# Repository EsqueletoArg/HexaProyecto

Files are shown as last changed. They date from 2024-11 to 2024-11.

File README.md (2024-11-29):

# HexaProyecto

Es  ajedrez de 3x3 casillas, donde se enfrentan 3 peones de ambos bandos para inmovilizar al rival o llegar al otro lado del tablero.

# Software:
* Programado para ser subido en un ESP32, este proyecto cuenta con un algoritmo que actua como el rival de este ajedrez. Este software se encuentra en la carpeta **/Firmware**, en el archivo nombrado "*HexaProyecto.ino*" y fue programado a mano usando Arduino IDE. Si desean construir uno en sus hogares, en las primeras lineas de esta programacion deberían cambiar ciertos valores para que el proyecto pueda conectarse a internet correctamente.

* En cuanto al servidor, se encuentra alojado en la carpeta **/Firmware/Server** en el archivo "*Servidor.js*". Para hacerlo funcionar, necesitamos descargar los programas Node.js y Mosquitto, ambos son descargables de manera gratuita en su respectiva página oficial. 

* Para hacerlo funcionar correctamente, hay que descargar ciertas dependencias en la carpeta donde se encuentre el servidor. Estas dependencias no funcionaran sin Nodejs y/o Mosquitto. Para descargarlas hay que dirigirse al directorio donde se encuentra el archivo "*Servidor.js*" via cmd e introducir los comandos "*npm init -y*" y "*npm install mqtt express body-parser*". Descargar cada dependencia podría tardar un tiempo, pero no de manera significativa.

# Hardware (PCB):
* El hardware de la PCB se encuentra en la carpeta **/Hardware_(PCB)**. Cada archivo dentro de esta carpeta es parte del diseño del PCB, desde el PCB final, hasta el esquema usado como referencia.

* Como el ESP32 está conectado al internet, esto reducía enormemente la cantidad de pines (Entradas y salidas), que podiamos usar. Por eso decidimos hacer una matriz de botones, lo que nos permitio reducir la cantidad de pines usados de 9 a 6.

* Para la placa usamos unos LEDs inteligentes llamados "WS2812", que con cierto nivel de programación son capaces de formar cualquier color. Estos LEDs solo necesitan una fuente de alimentacion de 5V, GND y una entrada de datos. Estos LEDs tambien tienen un cable de salida de datos que nos permitió poner 9 LEDs en serie y, por tanto, usar una sola salida del ESP32.

# Hardware (3D):
* Para el 3D hicimos un marco para encajar la PCB. Si bien puede sonar a que es por motivos de poco esfuerzo, la verdad es otra: Es algo simple, barato y que le permite al PCB relucir todo el esfuerzo que le dedicamos para diseñarlo.

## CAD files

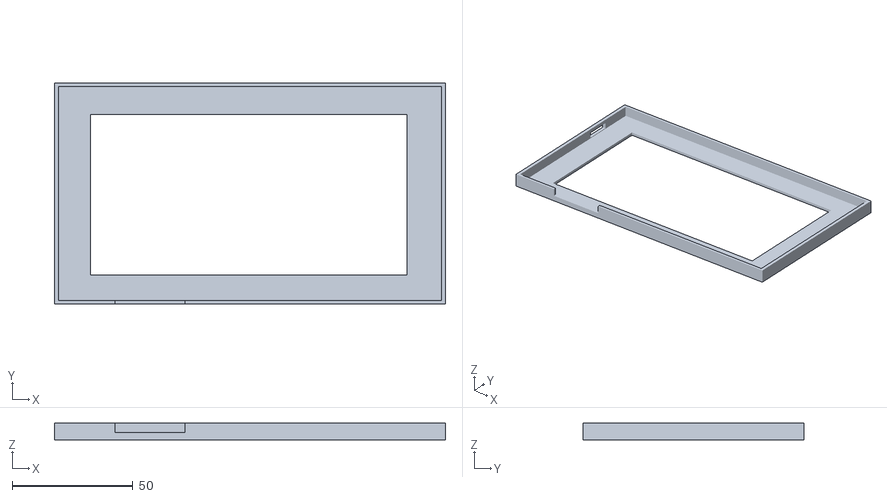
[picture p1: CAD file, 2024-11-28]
Hardware_(3D)/HexaProyecto_3D.stl
162.0 x 91.5 x 7.00

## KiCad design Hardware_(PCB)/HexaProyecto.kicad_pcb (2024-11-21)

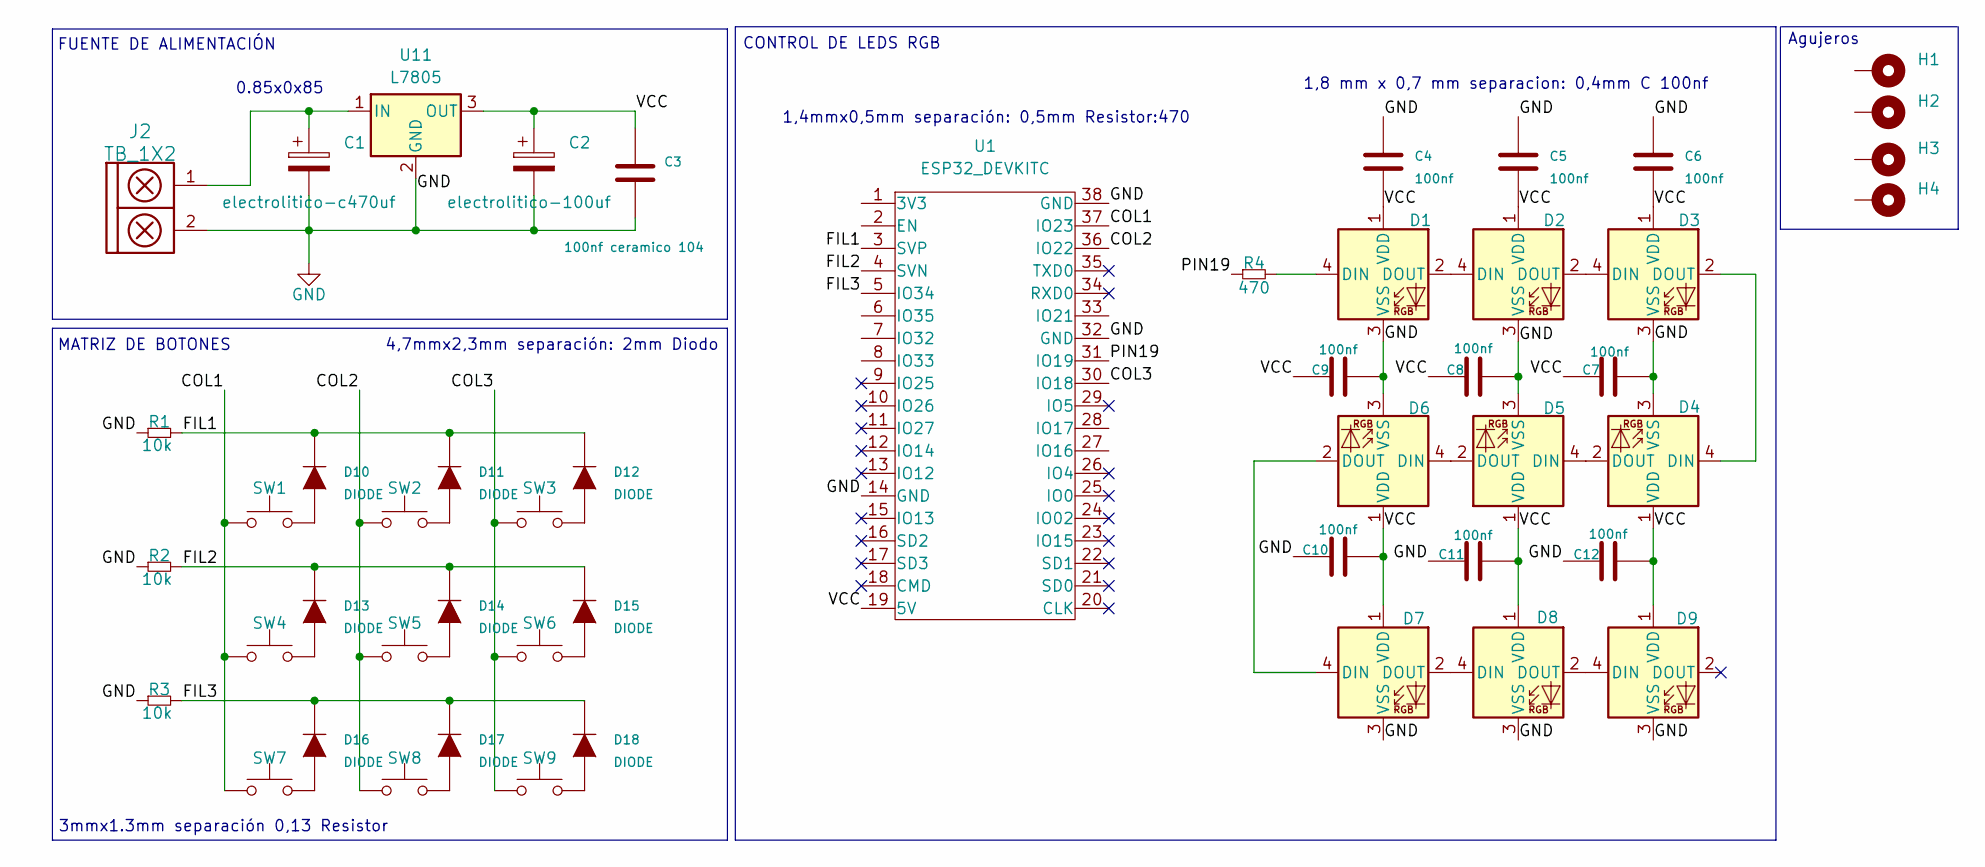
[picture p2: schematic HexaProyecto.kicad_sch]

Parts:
C1: electrolitico-c470uf; CP_Elec_6.3x9.9
C2: electrolitico-100uf; CP_Radial_D8.0mm_P3.50mm
C3: 100nf ceramico 104; CAP_0.1
C4, C5, C6, C7, C8, C9, C10, C11, C12: 100nf; verdadero.capacior.smd.100nf
D1, D2, D3, D4, D5, D6, D7, D8, D9: WS2812B; LED_WS2812B_PLCC4_5.0x5.0mm_P3.2mm
D10, D11, D12, D13, D14, D15, D16, D17, D18: DIODE; Diodo_SMD M7
H1, H2, H3, H4: MountingHole_Pad; Separador_M3_10mm
J2: TB_1X2; TerminalBlock_Altech_AK300-2_P5.00mm
R1, R2, R3: 10k; rrr
R4: 470; R_0603_1608Metric
SW1, SW2, SW3, SW4, SW5, SW6, SW7, SW8, SW9: SW_Push; pushbuttom
U1: ESP32_DEVKITC; ese
U11: L7805; TO-263-2

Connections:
/COL1: SW1.1, SW4.1, SW7.1, U1.37 (IO23)
/COL2: SW2.1, SW5.1, SW8.1, U1.36 (IO22)
/COL3: SW3.1, SW6.1, SW9.1, U1.30 (IO18)
/FIL1: D10.2 (K), D11.2 (K), D12.2 (K), R1.2, U1.3 (SVP)
/FIL2: D13.2 (K), D14.2 (K), D15.2 (K), R2.2, U1.4 (SVN)
/FIL3: D16.2 (K), D17.2 (K), D18.2 (K), R3.2, U1.5 (IO34)
/PIN19: R4.1, U1.31 (IO19)
/VCC: C2.1, C3.2, C4.1, C5.1, C6.1, C7.1, C8.1, C9.1, C10.1, C11.1, C12.1, D1.1 (VDD), D2.1 (VDD), D3.1 (VDD), D4.1 (VDD), D5.1 (VDD), D6.1 (VDD), D7.1 (VDD), D8.1 (VDD), D9.1 (VDD), U1.19 (5V), U11.3 (OUT)
GND: C1.2, C2.2, C3.1, C4.2, C5.2, C6.2, C7.2, C8.2, C9.2, C10.2, C11.2, C12.2, D1.3 (VSS), D2.3 (VSS), D3.3 (VSS), D4.3 (VSS), D5.3 (VSS), D6.3 (VSS), D7.3 (VSS), D8.3 (VSS), D9.3 (VSS), J2.2, R1.1, R2.1, R3.1, U1.14 (GND), U1.32 (GND), U1.38 (GND), U11.2 (GND)
unnamed: D1.4 (DIN), R4.2
unnamed: D1.2 (DOUT), D2.4 (DIN)
unnamed: D2.2 (DOUT), D3.4 (DIN)
unnamed: D3.2 (DOUT), D4.4 (DIN)
unnamed: D4.2 (DOUT), D5.4 (DIN)
unnamed: D5.2 (DOUT), D6.4 (DIN)
unnamed: D6.2 (DOUT), D7.4 (DIN)
unnamed: D7.2 (DOUT), D8.4 (DIN)
unnamed: D8.2 (DOUT), D9.4 (DIN)
unnamed: D10.1 (A), SW1.2
unnamed: D11.1 (A), SW2.2
unnamed: D12.1 (A), SW3.2
unnamed: D13.1 (A), SW4.2
unnamed: D14.1 (A), SW5.2
unnamed: D15.1 (A), SW6.2
unnamed: D16.1 (A), SW7.2
unnamed: D17.1 (A), SW8.2
unnamed: D18.1 (A), SW9.2
unnamed: C1.1, J2.1, U11.1 (IN)

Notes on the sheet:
FUENTE DE ALIMENTACIÓN
0.85x0x85
3mmx1.3mm separación 0,13 Resistor
1,8 mm x 0,7 mm separacion: 0,4mm C 100nf
MATRIZ DE BOTONES
Agujeros
CONTROL DE LEDS RGB
4,7mmx2,3mm separación: 2mm Diodo
1,4mmx0,5mm separación: 0,5mm Resistor:470

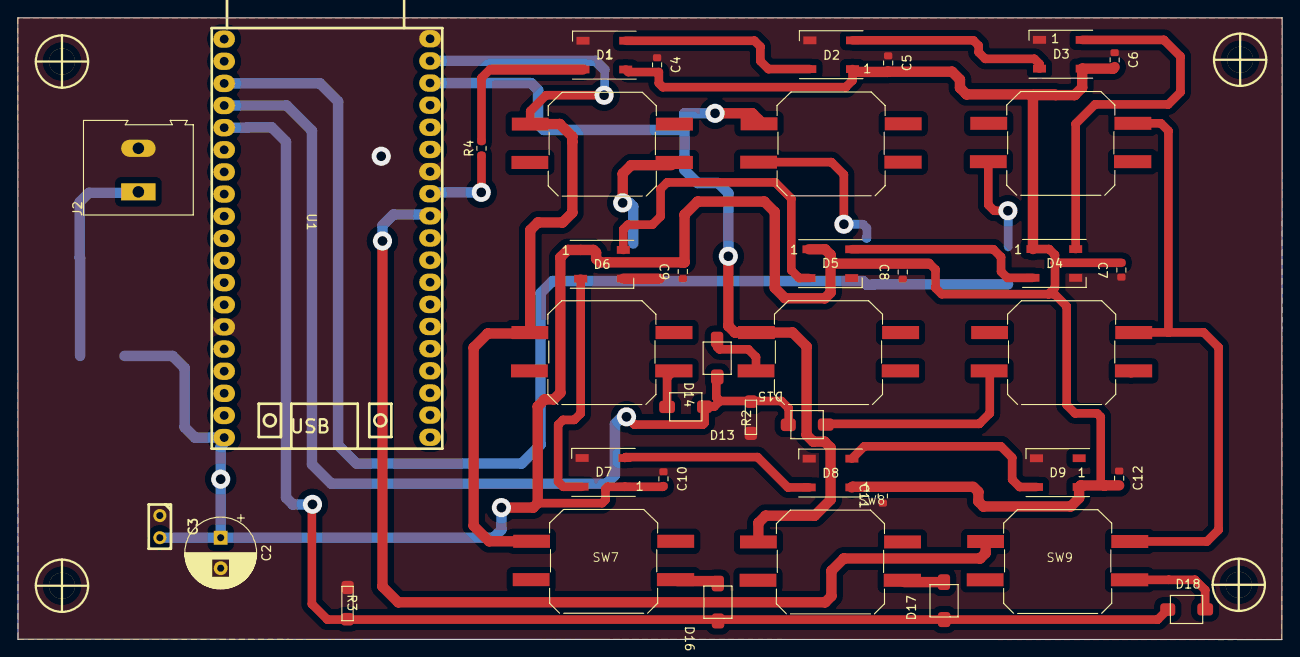
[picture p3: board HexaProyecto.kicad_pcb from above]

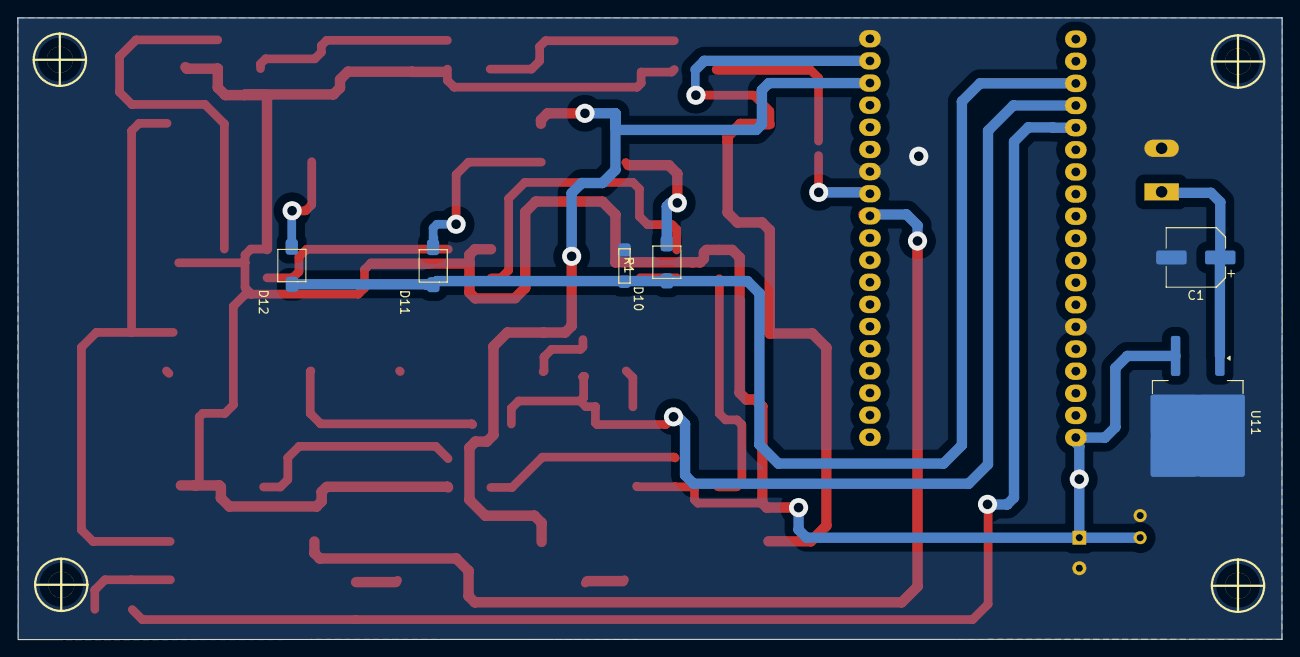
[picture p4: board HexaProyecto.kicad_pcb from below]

Board: 2 copper layers, 145.1 x 71.3 mm, 50 parts (6 on the bottom side), 28 nets.

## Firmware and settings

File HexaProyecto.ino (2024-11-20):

// Librerias:
#include <WiFi.h>
#include <HttpClient.h>
#include <PubSubClient.h>
#include <ArduinoJson.h>
#include <Adafruit_NeoPixel.h>

// Constantes iniciales:

#define DELAY 100
#define INICIO 0
#define FIN 9

// Constantes para el wifi:

const char SSID[] = "RoloWiFi"; //Nombre de la red
const char PASS[] = "12345678"; //Contraseña
const char* mqtt_server = "test.mosquitto.org";

WiFiClient espClient;
PubSubClient client(espClient);

// Constantes para la matriz:

#define FIL 3
#define COL 3

// Costantes para los pixeles:

#define PIN 19
#define NUM_PIX 9

Adafruit_NeoPixel pixels = Adafruit_NeoPixel(NUM_PIX, PIN, NEO_GRB + NEO_KHZ800);
// Estados:

#define ESTADO_REPOSO 0
#define ESTADO_INICIOV 1
#define ESTADO_INICIO 2
#define ESTADO_ACCIONADO 3
#define ESTADO_TDATOS 4
#define ESTADO_RESPUESTA 5

// Turnos:

#define TUTURNO 1
#define MITURNO 0

// Variables:

int i;
int estado;
int turno;
int cturno;
int vec;
char aux;
int victoria;
int doc;
int selec;
int a;

// Variables vectoriales enteras:

int filas[] = { 36, 39, 34 };
int columnas[] = { 23, 22, 18 };

// Matrizes:
bool matriz[FIL][COL];
bool vector[9];

// Coordenadas:

int ul;
int uc;
int ur;

int cl;
int cc;
int cr;

int dl;
int dc;
int dr;

int espacios;

// Ininiciacion de piexeles:

void callback(char* topic, byte* message, unsigned int length) {
  Serial.print("Message arrived [");
  Serial.print(topic);
  Serial.print("] ");
  for (unsigned int i = 0; i < length; i++) {
    Serial.print((char)message[i]);
  }
  Serial.println();
}

void reconnect() {
  while (!client.connected()) {
    Serial.print("Attempting MQTT connection...");
    String clientId = "ESP32Client-";
    clientId += String(random(0xffff), HEX);  // Add a unique identifier to the client ID
    if (client.connect(clientId.c_str())) {
      Serial.println("connected");
      client.subscribe("Respuesta");
    } else {
      Serial.print("failed, rc=");
      Serial.print(client.state());
      Serial.println(" try again in 5 seconds");
      delay(5000);
    }
  }
}

void ConectarInternet() {

  Serial.println();
  Serial.print("Connecting to ");
  Serial.println(SSID);

  WiFi.begin(SSID, PASS);

  while (WiFi.status() != WL_CONNECTED) {
    delay(500);
    Serial.print(".");
  }

  Serial.println("");
  Serial.print("Connected to WiFi network with IP Address: ");
  Serial.println(WiFi.localIP());
}

void setup() {
  setup_wifi();
  pixels.begin();
  ConectarInternet();
  Serial.begin(115200);

  client.setServer(mqtt_server, 1883);
  client.setCallback(callback);


  for (int i = 0; i < FIL; i++) {
    pinMode(filas[i], INPUT);
  }
  for (int i = 0; i < COL; i++) {
    pinMode(columnas[i], INPUT);
  }

  Inicial();
}

void setup_wifi() {
  delay(10);
  Serial.println();
  Serial.print("Connecting to ");
  Serial.println(SSID);

  WiFi.begin(SSID, PASS);

  while (WiFi.status() != WL_CONNECTED) {
    delay(500);
    Serial.print(".");
  }

  Serial.println("");
  Serial.println("WiFi connected");
  Serial.println("IP address: ");
  Serial.println(WiFi.localIP());
}

void leerMatriz() {

  vec = 0;

  for (int i = INICIO; i < COL; i++) {

    pinMode(columnas[i], OUTPUT);
    digitalWrite(columnas[i], HIGH);

    for (int j = INICIO; j < FIL; j++) {

      matriz[i][j] = digitalRead(filas[j]);

      vector[vec] = matriz[j][i];
      vec = vec + 1;
    }
    pinMode(columnas[i], INPUT);
  }
}

void MostrarMatriz() {
  Serial.println();
  for (int i = INICIO; i < COL; i++) {
    for (int j = INICIO; j < FIL; j++) {
      Serial.print(matriz[j][i]);
    }
    Serial.println(" ");
  }
}

void Inicial() {

  pixels.setPixelColor(0, pixels.Color(5, 0, 0));
  pixels.setPixelColor(1, pixels.Color(5, 0, 0));
  pixels.setPixelColor(2, pixels.Color(5, 0, 0));
  ul = 2;
  uc = 2;
  ur = 2;

  pixels.setPixelColor(3, pixels.Color(0, 0, 0));
  pixels.setPixelColor(4, pixels.Color(0, 0, 0));
  pixels.setPixelColor(5, pixels.Color(0, 0, 0));
  cl = 0;
  cc = 0;
  cr = 0;

  pixels.setPixelColor(6, pixels.Color(0, 5, 0));
  pixels.setPixelColor(7, pixels.Color(0, 5, 0));
  pixels.setPixelColor(8, pixels.Color(0, 5, 0));
  dl = 1;
  dc = 1;
  dr = 1;

  pixels.show();

  victoria = 0;

  turno = 0;
  cturno = 1;
}

void Hexapawn() {

  switch (turno) {
    case MITURNO:

      Seleccionar();
      Mover();
      Espacios();
      ChequearVictoriaMio();
      break;

    case TUTURNO:
      if (cturno == 2) {
        CondicionalesT2();
        cturno = cturno + 1;
      }
      if (cturno == 4) {
        CondicionalesT4();
        cturno = cturno + 1;
      }
      if (cturno == 6) {
        CondicionalesT6();
        cturno = cturno + 1;
      }

      ChequearVictoriaTuyo();
      Espacios();
      break;
  }
}

void Seleccionar() {
  if (vector[0] && selec != 1 && ul == 1) {
    selec = 1;
  }
  if (vector[1] && selec != 2 && uc == 1) {
    selec = 2;
  }
  if (vector[2] && selec != 3 && ur == 1) {
    selec = 3;
  }
  if (vector[3] && selec != 4 && cl == 1) {
    selec = 4;
  }
  if (vector[4] && selec != 5 && cc == 1) {
    selec = 5;
  }
  if (vector[5] && selec != 6 && cr == 1) {
    selec = 6;
  }
  if (vector[6] && selec != 7 && dl == 1) {
    selec = 7;
  }
  if (vector[7] && selec != 8 && dc == 1) {
    selec = 8;
  }
  if (vector[8] && selec != 9 && dr == 1) {
    selec = 9;
  }
}

void Mover() {
  if (dl == 1 && selec == 7 && vector[3] && cl == 0) {
    dl = 0;
    cl = 1;
    selec = 0;
    turno = 1;
    cturno = cturno + 1;
  }
  if (dl == 1 && selec == 7 && vector[4] && cc == 2) {
    dl = 0;
    cc = 1;
    selec = 0;
    turno = 1;
    cturno = cturno + 1;
  }
  if (dc == 1 && selec == 8 && vector[3] && cl == 2) {
    dc = 0;
    cl = 1;
    selec = 0;
    turno = 1;
    cturno = cturno + 1;
  }
  if (dc == 1 && selec == 8 && vector[4] && cc == 0) {
    dc = 0;
    cc = 1;
    selec = 0;
    turno = 1;
    cturno = cturno + 1;
  }
  if (dc == 1 && selec == 8 && vector[5] && cr == 2) {
    dc = 0;
    cr = 1;
    selec = 0;
    turno = 1;
    cturno = cturno + 1;
  }
  if (dr == 1 && selec == 9 && vector[4] && cc == 2) {
    dr = 0;
    cc = 1;
    selec = 0;
    turno = 1;
    cturno = cturno + 1;
  }
  if (dr == 1 && selec == 9 && vector[5] && cr == 0) {
    dr = 0;
    cr = 1;
    selec = 0;
    turno = 1;
    cturno = cturno + 1;
  }

  if (cl == 1 && selec == 4 && vector[0] && ul == 0) {
    cl = 0;
    ul = 1;
    selec = 0;
    turno = 1;
    cturno = cturno + 1;
  }
  if (cl == 1 && selec == 4 && vector[1] && uc == 2) {
    cl = 0;
    uc = 1;
    selec = 0;
    turno = 1;
    cturno = cturno + 1;
  }
  if (cc == 1 && selec == 5 && vector[0] && ul == 2) {
    cc = 0;
    ul = 1;
    selec = 0;
    turno = 1;
    cturno = cturno + 1;
  }
  if (cc == 1 && selec == 5 && vector[1] && uc == 0) {
    cc = 0;
    uc = 1;
    selec = 0;
    turno = 1;
    cturno = cturno + 1;
  }
  if (cc == 1 && selec == 5 && vector[2] && ur == 2) {
    cc = 0;
    ur = 1;
    selec = 0;
    turno = 1;
    cturno = cturno + 1;
  }
  if (cr == 1 && selec == 6 && vector[1] && uc == 2) {
    cr = 0;
    uc = 1;
    selec = 0;
    turno = 1;
    cturno = cturno + 1;
  }
  if (cr == 1 && selec == 6 && vector[2] && ur == 0) {
    cr = 0;
    ur = 1;
    selec = 0;
    turno = 1;
    cturno = cturno + 1;
  }
}

void MostrarLeds() {
  if (ul == 0) {
    pixels.setPixelColor(0, pixels.Color(0, 0, 0));
    pixels.show();
  }
  if (ul == 1) {
    pixels.setPixelColor(0, pixels.Color(0, 5, 0));
    pixels.show();
  }
  if (ul == 2) {
    pixels.setPixelColor(0, pixels.Color(5, 0, 0));
    pixels.show();
  }
  if (uc == 0) {
    pixels.setPixelColor(1, pixels.Color(0, 0, 0));
    pixels.show();
  }
  if (uc == 1) {
    pixels.setPixelColor(1, pixels.Color(0, 5, 0));
    pixels.show();
  }
  if (uc == 2) {
    pixels.setPixelColor(1, pixels.Color(5, 0, 0));
    pixels.show();
  }
  if (ur == 0) {
    pixels.setPixelColor(2, pixels.Color(0, 0, 0));
    pixels.show();
  }
  if (ur == 1) {
    pixels.setPixelColor(2, pixels.Color(0, 5, 0));
    pixels.show();
  }
  if (ur == 2) {
    pixels.setPixelColor(2, pixels.Color(5, 0, 0));
    pixels.show();
  }
  if (cl == 0) {
    pixels.setPixelColor(5, pixels.Color(0, 0, 0));
    pixels.show();
  }
  if (cl == 1) {
    pixels.setPixelColor(5, pixels.Color(0, 5, 0));
    pixels.show();
  }
  if (cl == 2) {
    pixels.setPixelColor(5, pixels.Color(5, 0, 0));
    pixels.show();
  }
  if (cc == 0) {
    pixels.setPixelColor(4, pixels.Color(0, 0, 0));
    pixels.show();
  }
  if (cc == 1) {
    pixels.setPixelColor(4, pixels.Color(0, 5, 0));
    pixels.show();
  }
  if (cc == 2) {
    pixels.setPixelColor(4, pixels.Color(5, 0, 0));
    pixels.show();
  }
  if (cr == 0) {
    pixels.setPixelColor(3, pixels.Color(0, 0, 0));
    pixels.show();
  }
  if (cr == 1) {
    pixels.setPixelColor(3, pixels.Color(0, 5, 0));
    pixels.show();
  }
  if (cr == 2) {
    pixels.setPixelColor(3, pixels.Color(5, 0, 0));
    pixels.show();
  }
  if (dl == 0) {
    pixels.setPixelColor(6, pixels.Color(0, 0, 0));
    pixels.show();
  }
  if (dl == 1) {
    pixels.setPixelColor(6, pixels.Color(0, 5, 0));
    pixels.show();
  }
  if (dl == 2) {
    pixels.setPixelColor(6, pixels.Color(5, 0, 0));
    pixels.show();
  }
  if (dc == 0) {
    pixels.setPixelColor(7, pixels.Color(0, 0, 0));
    pixels.show();
  }
  if (dc == 1) {
    pixels.setPixelColor(7, pixels.Color(0, 5, 0));
    pixels.show();
  }
  if (dc == 2) {
    pixels.setPixelColor(7, pixels.Color(5, 0, 0));
    pixels.show();
  }
  if (dr == 0) {
    pixels.setPixelColor(8, pixels.Color(0, 0, 0));
    pixels.show();
  }
  if (dr == 1) {
    pixels.setPixelColor(8, pixels.Color(0, 5, 0));
    pixels.show();
  }
  if (dr == 2) {
    pixels.setPixelColor(8, pixels.Color(5, 0, 0));
    pixels.show();
  }
}

void ChequearVictoriaMio() {
  if (ul == 1 || uc == 1 || ur == 1) {
    //111
    //000
    //000
    victoria = 1;
  }
  if (ul == 2 && !uc && ur == 2 && cl == 1 && cc == 2 && cr == 1 && !dl && dc == 1 && !dr && turno) {
    //202
    //121
    //010
    victoria = 1;
  }
  if (!ul && uc == 2 && !ur && !cl && cc == 1 && !cr && !dl && !dc && !dr && turno){
    //020
    //010
    //000
    victoria = 1;
  }
}

void ChequearVictoriaTuyo() {
  if (dr == 2 || dc == 2 || dl == 2) {
    //000
    //000
    //222
    victoria = 2;
  }
  if (ul == 2 && !uc && !ur && cl == 1 && cc == 2 && !cr && !dl && dc == 1 && !dr && !turno) {
    //200
    //120 + MITURNO
    //010
    victoria = 2;
  }
  if (!ul && !uc && ur == 2 && !cl && cc == 2 && cr == 1 && !dl && dc == 1 && !dr && !turno) {
    //002
    //021 + MITURNO
    //010
    victoria = 2;
  }
  if (!ul && uc == 2 && !ur && !cl && cc == 1 && cr == 2 && !dl && !dc && dr == 1 && !turno) {
    //020
    //012 + MITURNO
    //001
    victoria = 2;
  }
  if (!ul && uc == 2 && !ur && cl == 2 && cc == 1 && !cr && dl == 1 && !dc && !dr && !turno) {
    //020
    //210 + MITURNO
    //100
    victoria = 2;
  }
  if (ul == 2 && !uc && !ur && cl == 1 && !cc && cr == 2 && !dl && !dc && dr == 1 && !turno) {
    //200
    //102 + MITURNO
    //001
    victoria = 2;
  }
  if (!ul && !uc && ur == 2 && cl == 2 && !cc && cr == 1 && dl == 1 && !dc && !dr && !turno) {
    //002
    //201 + MITURNO
    //100
    victoria = 2;
  }
  if (!ul && !uc && !ur && cl == 2 && cc == 2 && !cr && !dl && !dc && !dr) {
    //000
    //220
    //000
    victoria = 2;
  }
  if (!ul && !uc && !ur && !cl && cc == 2 && cr == 2 && !dl && !dc && !dr) {
    //000
    //022
    //000
    victoria = 2;
  }
}

void Espacios() {
  espacios = dr + (dc * 10) + (dl * 100) + (cr * 1000) + (cc * 10000) + (cl * 100000) + (ur * 1000000) + (uc * 10000000) + (ul * 100000000);
}

void CondicionalesT2() {
  if (ul == 2 && uc == 2 && ur == 2 && cl == 0 && cc == 1 && cr == 0 && dl == 1 && dc == 0 && dr == 1) {
    // 222
    // 010
    // 101
    a = random(0, 2);
    if (a == 0) {
      ul = 0;
      cl = 2;
      turno = 0;
    }
    if (a == 1) {
      ul = 0;
      cc = 2;
      turno = 0;
    }
  }

  if (ul == 2 && uc == 2 && ur == 2 && cl == 1 && cc == 0 && cr == 0 && dl == 0 && dc == 1 && dr == 1) {
    // 222
    // 100
    // 011
    a = random(0, 3);
    if (a == 0) {
      uc = 0;
      cc = 2;
      turno = 0;
    }
    if (a == 1) {
      uc = 0;
      cl = 2;
      turno = 0;
    }
    if (a == 2) {
      ur = 0;
      cr = 2;
      turno = 0;
    }
  }

  if (ul == 2 && uc == 2 && ur == 2 && cl == 0 && cc == 0 && cr == 1 && dl == 1 && dc == 1 && dr == 0) {
    // 222
    // 001
    // 110
    a = random(0, 3);
    if (a == 0) {
      uc = 0;
      cc = 2;
      turno = 0;
    }
    if (a == 1) {
      uc = 0;
      cr = 2;
      turno = 0;
    }
    if (a == 2) {
      ul = 0;
      cl = 2;
      turno = 0;
    }
  }
}

void CondicionalesT4() {
  if (ul == 2 && uc == 0 && ur == 2 && cl == 2 && cc == 1 && cr == 0 && dl == 0 && dc == 0 && dr == 1) {
    // 202
    // 210
    // 001
    a = random(0, 4);
    if (a == 0) {
      cl = 0;
      dl = 2;
      turno = 0;
    }
    if (a == 1) {
      ur = 0;
      cl = 2;
      turno = 0;
    }
    if (a == 2) {
      ul = 0;
      cc = 2;
      turno = 0;
    }
    if (a == 3) {
      ur = 0;
      cc = 2;
      turno = 0;
    }
  }

  if (ul == 0 && uc == 2 && ur == 2 && cl == 1 && cc == 2 && cr == 0 && dl == 0 && dc == 0 && dr == 1) {
    // 022
    // 120
    // 001
    a = random(0, 4);
    if (a == 0) {
      uc = 0;
      cl = 2;
      turno = 0;
    }
    if (a == 1) {
      ur = 0;
      cr = 2;
      turno = 0;
    }
    if (a == 2) {
      cc = 0;
      dc = 2;
      turno = 0;
    }
    if (a == 3) {
      cc = 0;
      dr = 2;
      turno = 0;
    }
  }

  if (ul == 2 && uc == 0 && ur == 2 && cl == 1 && cc == 1 && cr == 0 && dl == 0 && dc == 1 && dr == 0) {
    // 202
    // 110
    // 010
    a = random(0, 3);
    if (a == 0) {
      ul = 0;
      cc = 2;
      turno = 0;
    }
    if (a == 1) {
      ur = 0;
      cc = 2;
      turno = 0;
    }
    if (a == 2) {
      ur = 0;
      cr = 2;
      turno = 0;
    }
  }

  if (ul == 2 && uc == 2 && ur == 0 && cl == 1 && cc == 0 && cr == 1 && dl == 0 && dc == 0 && dr == 1) {
    // 220
    // 101
    // 001
    a = random(0, 3);
    if (a == 0) {
      uc = 0;
      cl = 2;
      turno = 0;
    }
    if (a == 1) {
      uc = 0;
      cr = 2;
      turno = 0;
    }
    if (a == 2) {
      uc = 0;
      cc = 2;
      turno = 0;
    }
  }

  if (ul == 0 && uc == 2 && ur == 2 && cl == 0 && cc == 2 && cr == 1 && dl == 1 && dc == 0 && dr == 0) {
    // 022
    // 021
    // 100
    a = random(0, 3);
    if (a == 0) {
      uc = 0;
      cr = 2;
      turno = 0;
    }
    if (a == 1) {
      cc = 0;
      dc = 2;
      turno = 0;
    }
    if (a == 2) {
      cc = 0;
      dl = 2;
      turno = 0;
    }
  }

  if (ul == 0 && uc == 2 && ur == 2 && cl == 2 && cc == 1 && cr == 1 && dl == 1 && dc == 0 && dr == 0) {
    // 022
    // 211
    // 100
    a = random(0, 2);
    if (a == 0) {
      uc = 0;
      cr = 2;
      turno = 0;
    }
    if (a == 1) {
      ur = 0;
      cc = 2;
      turno = 0;
    }
  }

  if (ul == 2 && uc == 0 && ur == 2 && cl == 2 && cc == 0 && cr == 1 && dl == 0 && dc == 1 && dr == 0) {
    // 202
    // 201
    // 010
    a = random(0, 2);
    if (a == 0) {
      cl = 0;
      dl = 2;
      turno = 0;
    }
    if (a == 1) {
      cl = 0;
      dc = 2;
      turno = 0;
    }
  }

  if (ul == 2 && uc == 2 && ur == 0 && cl == 1 && cc == 1 && cr == 2 && dl == 0 && dc == 0 && dr == 1) {
    // 220
    // 112
    // 001
    a = random(0, 2);
    if (a == 0) {
      ul = 0;
      cc = 2;
      turno = 0;
    }
    if (a == 1) {
      uc = 0;
      cl = 2;
      turno = 0;
    }
  }

  if (ul == 0 && uc == 2 && ur == 2 && cl == 0 && cc == 1 && cr == 0 && dl == 0 && dc == 0 && dr == 1) {
    // 022
    // 010
    // 001
    a = random(0, 2);
    if (a == 0) {
      ur = 0;
      cc = 2;
      turno = 0;
    }
    if (a == 1) {
      ur = 0;
      cr = 2;
      turno = 0;
    }
  }

  if (ul == 0 && uc == 2 && ur == 2 && cl == 0 && cc == 1 && cr == 0 && dl == 1 && dc == 0 && dr == 0) {
    // 022
    // 010
    // 100
    a = random(0, 2);
    if (a == 0) {
      ur = 0;
      cc = 2;
      turno = 0;
    }
    if (a == 1) {
      ur = 0;
      cr = 2;
      turno = 0;
    }
  }

  if (ul == 2 && uc == 0 && ur == 2 && cl == 1 && cc == 0 && cr == 0 && dl == 0 && dc == 0 && dr == 1) {
    // 202
    // 100
    // 001
    ur = 0;
    cr = 2;
    turno = 0;
  }

  if (ul == 2 && uc == 0 && ur == 2 && cl == 0 && cc == 1 && cr == 2 && dl == 1 && dc == 0 && dr == 0) {
    // 202
    // 012
    // 100
    a = random(0, 4);
    if (a == 0) {
      cr = 0;
      dr = 2;
      turno = 0;
    }
    if (a == 1) {
      ul = 0;
      cl = 2;
      turno = 0;
    }
    if (a == 2) {
      ur = 0;
      cc = 2;
      turno = 0;
    }
    if (a == 3) {
      ul = 0;
      cc = 2;
      turno = 0;
    }
  }

  if (ul == 2 && uc == 0 && ur == 2 && cl == 0 && cc == 1 && cr == 1 && dl == 0 && dc == 1 && dr == 0) {
    // 202
    // 011
    // 010
    a = random(0, 3);
    if (a == 0) {
      ur = 0;
      cc = 2;
      turno = 0;
    }
    if (a == 1) {
      ul = 0;
      cc = 2;
      turno = 0;
    }
    if (a == 2) {
      ur = 0;
      cr = 2;
      turno = 0;
    }
  }

  if (ul == 0 && uc == 2 && ur == 2 && cl == 1 && cc == 0 && cr == 1 && dl == 1 && dc == 0 && dr == 0) {
    // 022
    // 101
    // 100
    a = random(0, 3);
    if (a == 0) {
      uc = 0;
      cr = 2;
      turno = 0;
    }
    if (a == 1) {
      uc = 0;
      cl = 2;
      turno = 0;
    }
    if (a == 2) {
      uc = 0;
      cc = 2;
      turno = 0;
    }
  }

  if (ul == 2 && uc == 0 && ur == 2 && cl == 1 && cc == 0 && cr == 2 && dl == 0 && dc == 1 && dr == 0) {
    // 202
    // 102
    // 010
    a = random(0, 2);
    if (a == 0) {
      cr = 0;
      dr = 2;
      turno = 0;
    }
    if (a == 1) {
      cr = 0;
      dc = 2;
      turno = 0;
    }
  }

  if (ul == 0 && uc == 2 && ur == 2 && cl == 2 && cc == 1 && cr == 1 && dl == 1 && dc == 0 && dr == 0) {
    // 022
    // 211
    // 100
    a = random(0, 2);
    if (a == 0) {
      ur = 0;
      cc = 2;
      turno = 0;
    }
    if (a == 1) {
      uc = 0;
      cr = 2;
      turno = 0;
    }
  }

  if (ul == 2 && uc == 0 && ur == 2 && cl == 0 && cc == 0 && cr == 1 && dl == 1 && dc == 0 && dr == 0) {
    // 202
    // 001
    // 100
    ul = 0;
    cl = 2;
    turno = 0;
  }
}
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
void loop() {
  MostrarMatriz();
  if (!client.connected()) {
    reconnect();
  }
  client.loop();
  leerMatriz();
  MostrarLeds();
  if (!victoria) {
    Hexapawn();
    StaticJsonDocument<200> doc;
    doc["Cords"] = espacios;
    char buffer[256];
    serializeJson(doc, buffer);
    client.publish("Mensaje", buffer);
  }
  MostrarLeds();
  if (victoria == 1) {
    delay(1000);
    for (int i = 0; i < 9; i++) {
      pixels.setPixelColor(i, pixels.Color(0, 10, 5));
      pixels.show();
      delay(250);
    }
    for (int i = 0; i < 9; i++) {
      pixels.setPixelColor(i, pixels.Color(0, 0, 0));
      pixels.show();
      delay(250);
    }
    Inicial();
  }

  if (victoria == 2) {
    delay(1000);
    for (int i = 0; i < 9; i++) {
      pixels.setPixelColor(i, pixels.Color(10, 5, 0));
      pixels.show();
      delay(250);
    }
    for (int i = 0; i < 9; i++) {
      pixels.setPixelColor(i, pixels.Color(0, 0, 0));
      pixels.show();
      delay(250);
    }
    Inicial();
  }
  delay(100);
}

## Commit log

2024-11-28 Update and rename lll.kicad_pcb to Hardware_(PCB)/HexaProyecto.kicad_pcb
    [HexaProyecto.kicad_pcb]
2024-11-28 Update and rename lll.kicad_sch to Hardware_(PCB)/HexaProyecto.kicad_sch
    [HexaProyecto.kicad_sch]
